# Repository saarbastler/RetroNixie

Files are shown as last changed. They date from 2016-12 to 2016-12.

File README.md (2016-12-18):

# RetroNixie

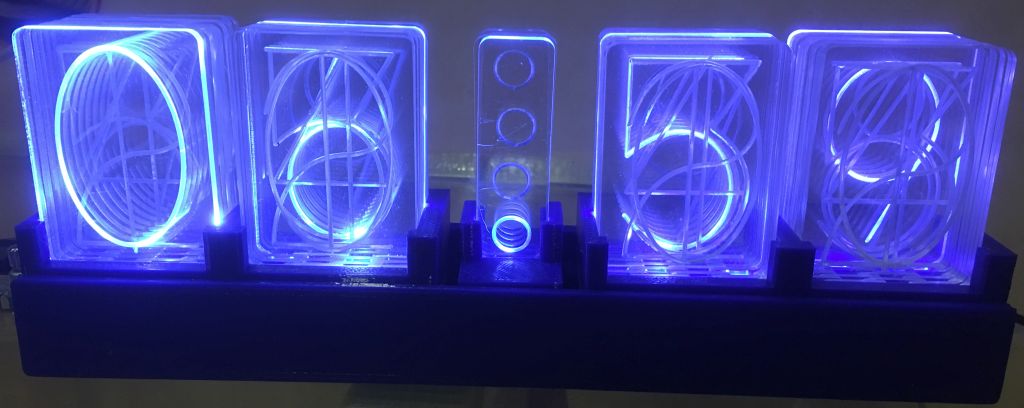
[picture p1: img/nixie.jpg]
Retro Nixie


RetroNixie is a 4 digit Clock looking like a Nixie tube clock, but is made of acrylic glass. Each digits has 10 acrylic glass slices, engraved with digits 0..9.
Each digit has got two WS2812 Led's, an ATMega328P controls the Led's to show the time.

See also on Thingiverse: (http://www.thingiverse.com/thing:1978456)

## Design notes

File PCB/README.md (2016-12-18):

# PCB Files

I'm using Target as PCB software. The Segment PCB is needed twice, the other once. The Clock is using an ATMega328P and a DS1307 as real time clock. A rotary encoder is used to set the time.

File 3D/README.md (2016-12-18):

# 3D Files

Designed in Open Scad. Print dualBoden.stl and vorne.stl twice and miniBoden once.

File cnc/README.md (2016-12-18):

# CNC Files

Use you favorite CAM software to generate the G Codes for you milling machine. I'm using [Estlcam](http://www.estlcam.com/) to generate the files for my [Stepcraft 420](https://www.stepcraft-systems.com/en/).

My machine is able to mill acrylic glass under water up to 30cm x 15cm. Three acrylic glass sheets are necessary to mill 4 * 10 digits and for smaller pieces with dots. first the digits are milled using a 45° graver, then use a 2mm milling tool to cut out the pieces.

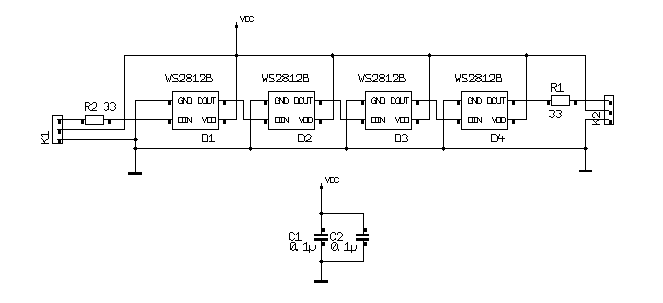
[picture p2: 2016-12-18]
PCB/DotsSegmentSchematics.png

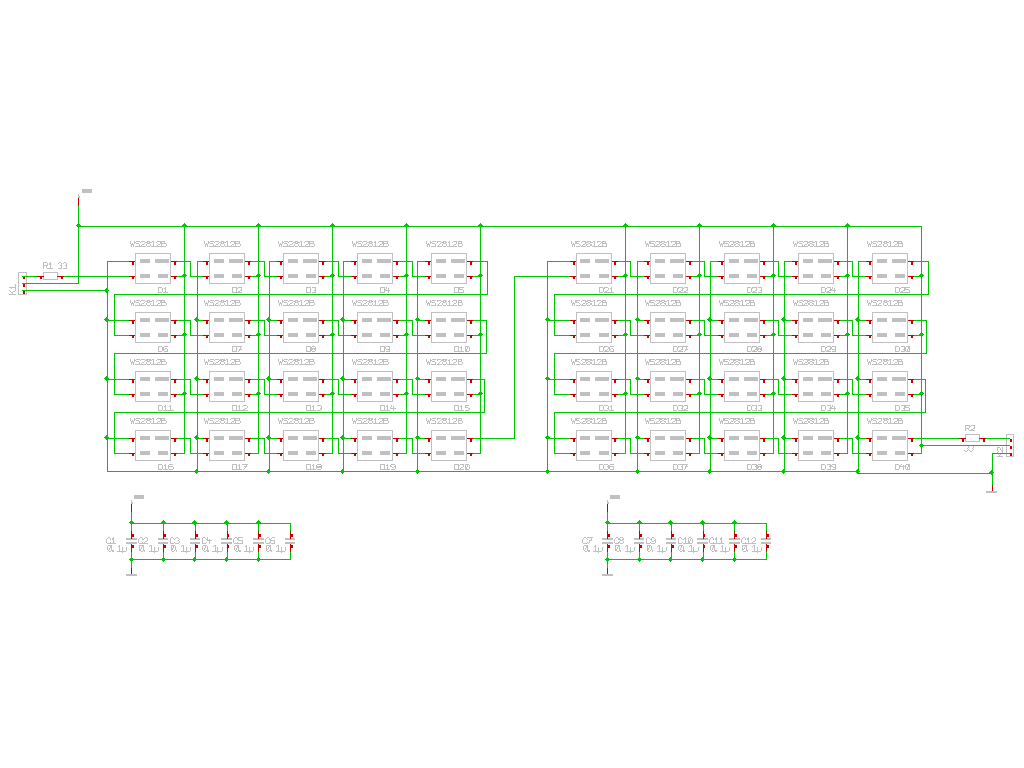
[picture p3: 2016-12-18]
PCB/DualDigitsSchematics.png

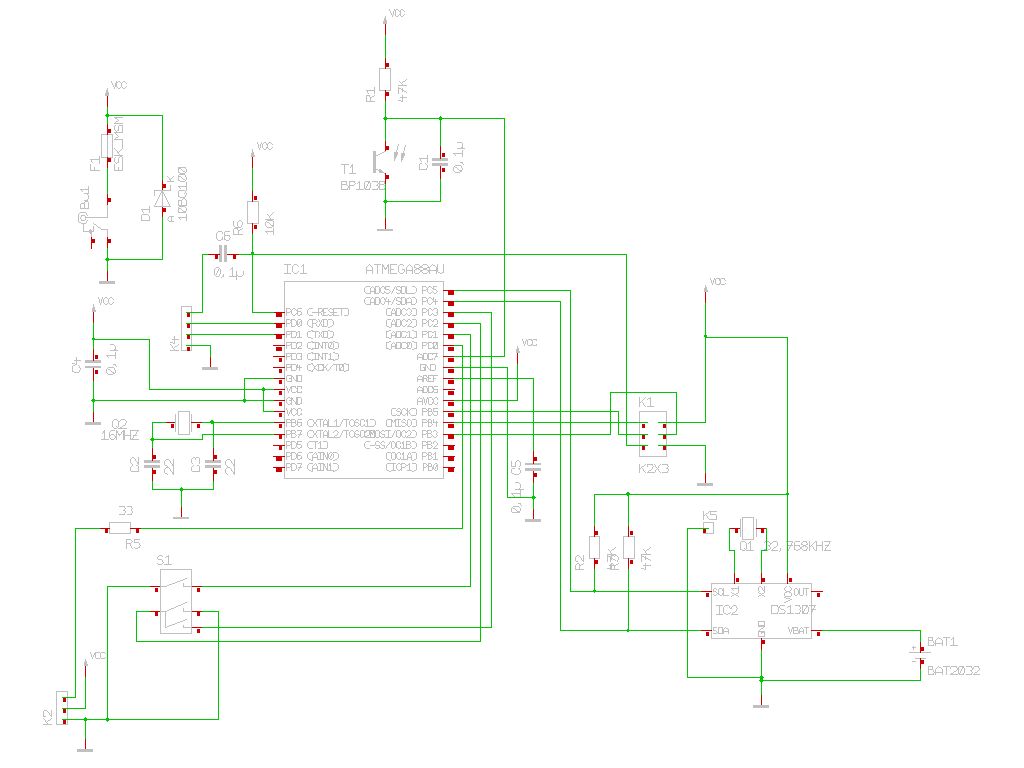
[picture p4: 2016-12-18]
PCB/ClockSchematics.png

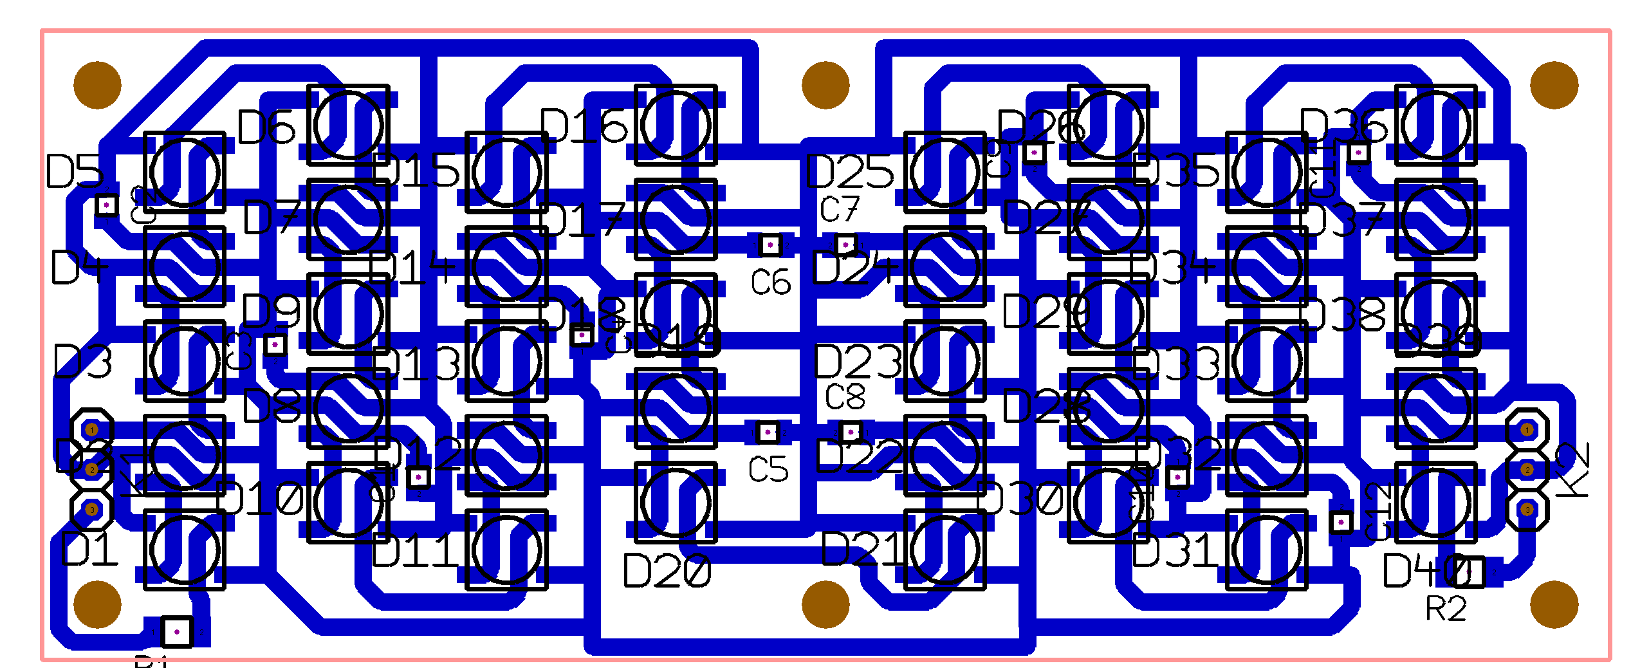
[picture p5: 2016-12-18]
PCB/DualDigitsPCB.png

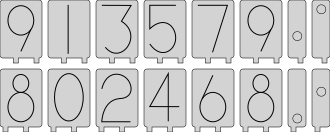
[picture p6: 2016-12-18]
cnc/digits3.png

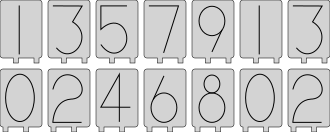
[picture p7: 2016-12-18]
cnc/digits1.png

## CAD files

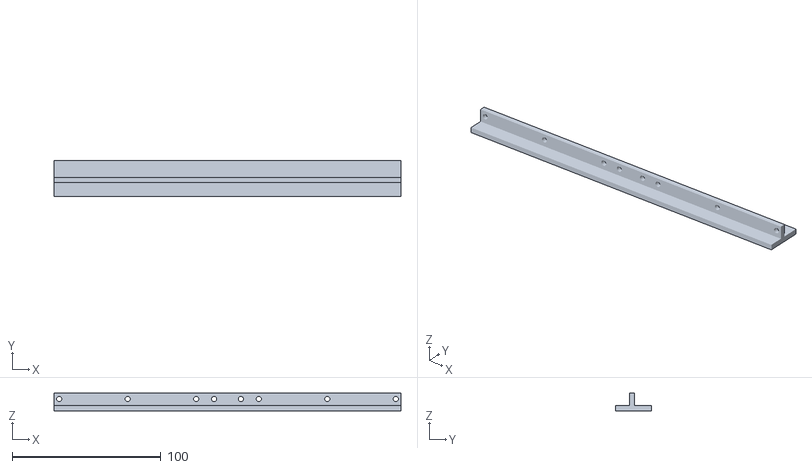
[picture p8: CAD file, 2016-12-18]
3D/vorne.stl
233.0 x 24.5 x 12.0

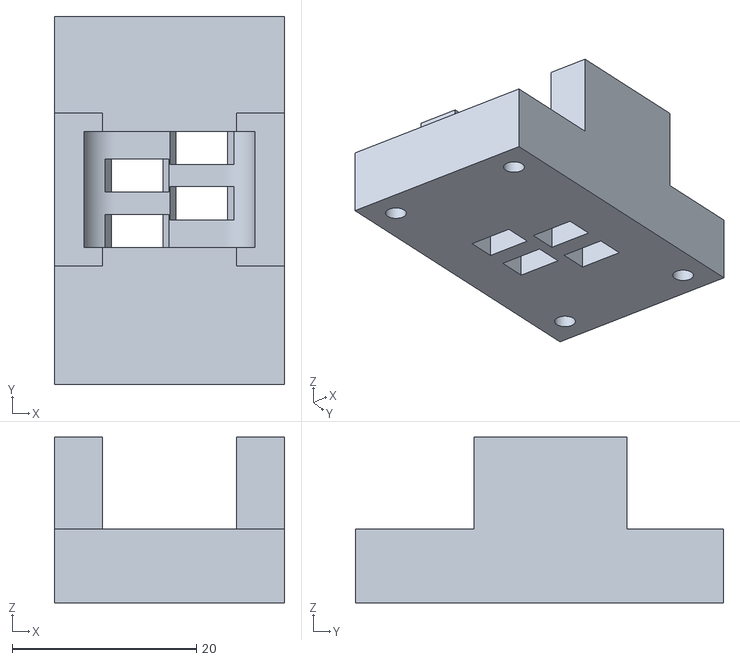
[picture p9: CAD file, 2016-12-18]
3D/miniBoden.stl
25.0 x 40.0 x 18.0

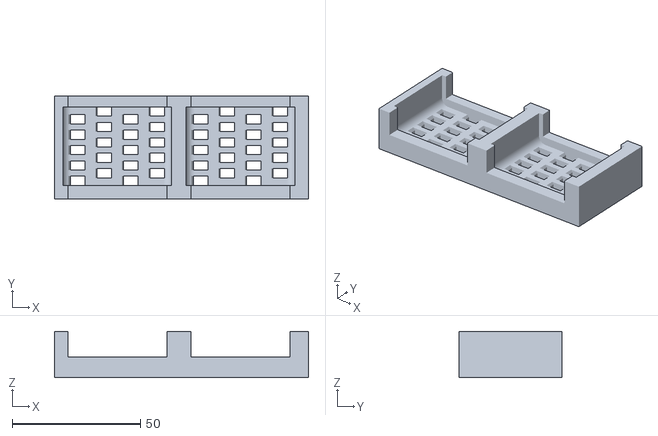
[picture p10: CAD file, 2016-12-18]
3D/dualBoden.stl
99.0 x 40.0 x 18.0

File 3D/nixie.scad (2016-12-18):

$fn=100;
addition= 0.3;

module ausschnitt()
{  
  rotate([90,0,0])translate([0,0,-1.5-addition])
  linear_extrude(height=3+2*addition)
    polygon(points=[[-2.5-addition,-1],[-2.5-addition,5-1-addition], [-2.5-1-addition,5+addition]
      , [2.5+1+addition,5+addition],[2.5+addition,5-1-addition],[2.5+addition,-1]
  
  ]);
}

module auschnittDigit()
{
  for(i=[0:4],n=[0:1])
  {
    translate([9+n*20.666,7+i*6,0]) ausschnitt();
    translate([9+10.333+n*20.666,10+i*6,0]) ausschnitt();
  }
  hull()
  {
    translate([6.5,7-1.5-addition,8])rotate([-90,0,0])cylinder(r=3+addition,h=30+2*addition);
    translate([42+.5,7-1.5-addition,8])rotate([-90,0,0])cylinder(r=3+addition,h=30+2*addition);
  }
  translate([3.5-addition/2,7-1.5-addition,8]) cube([42+addition,30+2*addition,20]);
}

module miniBoden()
{
  difference()
  {
    union()
    {
      cube([25,40,8]);
      
      difference()
      {
        translate([0,16.7-1.5-addition-2,8]) cube([25,12+(2+addition)*2,10]);
        
        translate([3.2+2,16.7-5,8]) cube([18.6-4,20,15]);
      }
    }
        
    translate([9,0,0]) 
    {
      translate([0,16.7,0]) ausschnitt();
      translate([7,16.7+3,0]) ausschnitt();
      translate([0,16.7+6,0]) ausschnitt();
      translate([7,16.7+9,0]) ausschnitt();
    }  
    
    hull()
    {
      translate([6.5,16.7-1.5-addition,8])rotate([-90,0,0])cylinder(r=3+addition,h=12+2*addition);
      translate([18+.5,16.7-1.5-addition,8])rotate([-90,0,0])cylinder(r=3+addition,h=12+2*addition);
    }
    
    translate([3.5-addition,16.7-1.5-addition,8]) cube([18+2*addition,12+2*addition,20]);
    
    translate([ 3.5, 3.5,-1]) cylinder(d=2.5,h=7);
    translate([ 3.5,36.5,-1]) cylinder(d=2.5,h=7);
    translate([21.5, 3.5,-1]) cylinder(d=2.5,h=7);
    translate([21.5,36.5,-1]) cylinder(d=2.5,h=7);

  }
}

module boden()
{
  difference()
  {
    union()
    {
      cube([99,40,8]);
      
      difference()
      {
        translate([0,0,8]) cube([99,40,10]);
        
        translate([3.2+2,-1,8]) cube([42+2*addition-4,50,15]);
        translate([48+3.2+2,-1,8]) cube([42+2*addition-4,50,15]);
      }
    }
    
    auschnittDigit();
    translate([48,0,0]) auschnittDigit();
    
    translate([ 3.5, 3.5,-1]) cylinder(d=2.5,h=7);
    translate([ 3.5,36.5,-1]) cylinder(d=2.5,h=6);
    translate([49.5, 3.5,-1]) cylinder(d=2.5,h=7);
    translate([49.5,36.5,-1]) cylinder(d=2.5,h=7);
    translate([95.5, 3.5,-1]) cylinder(d=2.5,h=7);
    translate([95.5,36.5,-1]) cylinder(d=2.5,h=7);
  }
}

module schraubAussparung()
{
  cylinder(d=3.5, h=10);
  cylinder(d=6.5, h=4.5);
}

module vorne()
{
  translate([0,-4.5,-5-3.75])
  {
    translate([0,0,-10]) cube([233,3.5,13]);
    *translate([0,0,-10]) cube([233,4,3]);
    difference()
    {
      translate([0,0,1.5]) cube([233,12,13]);
      translate([-1,3.5,5]) cube([240,20,20]);
      
      translate([ 3.5,8,-3]) schraubAussparung();
      translate([49.5,8,-3]) schraubAussparung();
      translate([95.5,8,-3]) schraubAussparung();
      
      translate([107.5,8,-3]) schraubAussparung();
      translate([107.5+18,8,-3]) schraubAussparung();
      
      translate([134,0,0])
      {
        translate([ 3.5,8,-3]) schraubAussparung();
        translate([49.5,8,-3]) schraubAussparung();
        translate([95.5,8,-3]) schraubAussparung();
      }
    }
  }
}

vorne();
translate([233,40,0]) rotate([0,0,180]) vorne();

boden();
translate([104,0,0]) miniBoden();
translate([134,0,0]) boden();

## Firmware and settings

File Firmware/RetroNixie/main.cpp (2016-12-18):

/*
 * MotorController.cpp
 *
 * Created: 04.10.2016 20:11:01
 * Author : Joerg
 */ 

#include <avr/io.h>
#include <avr/interrupt.h>
#include <avr/pgmspace.h>

#include "Device.h"
#include "Timer1.h"
#include "DelayTimerW.h"

#include "RetroNixieClock.h"
#include "I2CMaster.h"

/*extern "C"
{
  void __cxa_pure_virtual()
  {
    
  }
}*/

RetroNixieClock retroNixieClock;

int main(void)
{  
  sei();
  
  retroNixieClock.init();
  for(;;)
  {
    retroNixieClock.loop();
    idle();
  }
}

void idle()
{
  retroNixieClock.idle();
}

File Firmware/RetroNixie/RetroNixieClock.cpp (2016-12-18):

/* 
* RetroNixieClock.cpp
*
* Created: 20.11.2016 08:15:42
* Author: Joerg
*/

#include <avr/pgmspace.h>
#include <avr/io.h>
#include <string.h>

#include "Device.h"
#include "Timer1.h"

#include "RetroNixie.h"
#include "RetroNixieClock.h"

#include "I2CDS1307.h"
#include "I2CMaster.h"

#ifdef ENABLE_SERIAL_MONITOR
#include "PrintStream.h"
extern PrintStream out;
#endif

#define MODE_SHOW_TIME    0
#define MODE_SET_HOURS    1
#define MODE_SET_MINUTES  2
#define MODE_STORE_WAIT   3

// two bits red, green, blue. 00= off, 01= half bright, 10= full bright
const PROGMEM uint8_t RetroNixieClock::COLOR_BITS[] = { 
  /*0b000000, */0b000001, 0b000010, 0b000100, 0b000101, 0b000110, 0b001000, 0b001001, 0b001010,
  0b010000, 0b010001, 0b010010, 0b010100, 0b010101, 0b010110, 0b011000, 0b011001, 0b011010,
  0b100000, 0b100001, 0b100010, 0b100100, 0b100101, 0b100110, 0b101000, 0b101001, 0b101010 };
#define COLOR_BITS_SIZE     (sizeof(COLOR_BITS)/sizeof(COLOR_BITS[0]))

RetroNixieClock::RetroNixieClock() 
  : encoder(Timer1::getTickerLAddr(), this), 
  secondTimer( Timer1::getTickerAddr(), 100 ),
  milliseconds(0), seconds(0), time(0), timeInitialized(false)

{
  colorIndex= 0;
  brightness= 0x7f;
  setColor(brightness, colorIndex, color);

  off.r=0;
  off.g=0;
  off.b=0;

  mode= MODE_SHOW_TIME;
  clearDigitColor();

  ADMUX= _BV(REFS0) | /*_BV(ADLAR) |*/ 7;
  ADCSRA= _BV(ADEN) | _BV(ADATE) | _BV(ADIF) | 7;
  ADCSRB= 0;
  //DIDR0 = 1;

  ADCSRA |= _BV(ADSC);
  analogCount= 0;
  lastAnalogInput= 0;

  I2CMaster::init(80);
}

void RetroNixieClock::init()
{
  Timer1::init(  2, 14 );
  ICR1= 2000;

  LedString::init();
    
  secondTimer.start();    

  displayTime( time );
}

void RetroNixieClock::idle()
{
  encoder.cyclic();

  if( ADCSRA & _BV(ADIF) )
  {
    lastAnalogInput= ADC;
    analogIn += lastAnalogInput;
    ADCSRA= _BV(ADEN)  | _BV(ADATE) | _BV(ADIF) | 7;

    if( ++analogCount & 0xc0 )
    {
      analogCount= 0;
      setBrightness( 255 - (analogIn >> 8));
      analogIn= 0;
    }
  }
}

void RetroNixieClock::loop()
{
  if( secondTimer.isDone() )
  {
    secondTimer.start();
    milliseconds++;

    loop100ms();
  }
}

void RetroNixieClock::loop100ms()
{
  readRTC();

  if( ds1307.isDataAvailable() )
  {
    uint8_t dsSeconds= ds1307.getSeconds();
    if( seconds != dsSeconds )
    {
      milliseconds= 0;
      seconds= dsSeconds;
      time= ds1307.getHoursMinutes();

#ifdef ENABLE_SERIAL_MONITOR
      //out.printf_P( PSTR("TI: %wd %bd\r\n"), time, seconds);
#endif

      if( mode == MODE_SHOW_TIME)
      {
        displayTime( time );
      }
      else
      {
        uint8_t diff = *Timer1::getTickerLAddr() - modeTimeout;
        if( diff > 300 )
          setMode( MODE_SHOW_TIME );
      }
    }

    ds1307.resetDataAvailable();
  }

  timeSetLoop();
}

void RetroNixieClock::timeSetLoop()
{
  switch( mode )
  {
    case MODE_SET_HOURS:
    setColor( 15 + (setCounter<<4), setColorIndex, digitColor[0]);
    digitColor[1]= digitColor[0];

    if( setCounter >= 15 )
    {
      setCounterDir= -1;
    }
    else if( setCounter == 0 )
    {
      setCounterDir= 1;
      setColorIndex= (setColorIndex+1) % COLOR_BITS_SIZE;
    }

    setCounter += setCounterDir;
    
    RetroNixie::setNumber( timeSet, digitColor );
    LedString::transmit();
    break;
    case MODE_SET_MINUTES:
    setColor( 15 + (setCounter<<4), setColorIndex, digitColor[2]);
    digitColor[3]= digitColor[2];

    if( setCounter >= 15 )
    {
      setCounterDir= -1;
    }
    else if( setCounter == 0 )
    {
      setCounterDir= 1;
      setColorIndex= (setColorIndex+1) % COLOR_BITS_SIZE;
    }

    setCounter += setCounterDir;
    
    RetroNixie::setNumber( timeSet, digitColor );
    LedString::transmit();
    break;

    case MODE_STORE_WAIT:
    setColor( 15 + (setCounter<<4), setColorIndex, digitColor[0]);
    digitColor[1]= digitColor[0];
    digitColor[2]= digitColor[0];
    digitColor[3]= digitColor[0];

    if( setCounter != 0 )
    {
      setCounter--;
    }
    RetroNixie::setNumber( timeSet, digitColor );
    LedString::transmit();
    break;
  }
}

void RetroNixieClock::readRTC()
{
  if(!I2CMaster::isBusy())
  {
    if(ds1307.isModified())
    {
#ifdef ENABLE_SERIAL_MONITOR
      out.print_P(PSTR("write Device\r\n"));
#endif
      ds1307.writeDevice();

      if( I2CMaster::hasError())
      {
#ifdef ENABLE_SERIAL_MONITOR
        out.printf_P(PSTR("DS1307 Error: %bx\r\n"), I2CMaster::getError());
#endif
      }
    }
    else if( !ds1307.isDataAvailable() )
    {
#ifdef ENABLE_SERIAL_MONITOR
      if(!timeInitialized)
        out.print_P(PSTR("read Device\r\n"));
#endif
      ds1307.readDevice();
      
      if( I2CMaster::hasError())
      {
#ifdef ENABLE_SERIAL_MONITOR
        out.printf_P(PSTR("DS1307 Error: %bx\r\n"), I2CMaster::getError());
#endif
      }
      else
      {
        if( !ds1307.isClockEnabled() )
        {
          ds1307.enableClock(true);
        }
        else if(!timeInitialized)
        {
          seconds= ds1307.getSeconds();
          time= ds1307.getHoursMinutes();
          colorIndex= ds1307.getExtra(0);
          if( colorIndex >= COLOR_BITS_SIZE )
          colorIndex= 0;
        }

#ifdef ENABLE_SERIAL_MONITOR
        if(!timeInitialized)
        {
          for( BYTE b=0;b < 8;b++)
          {
            out.printHex( ds1307.buffer[b] );
            out.putch(' ');
          }
          out.crlf();
        }
#endif

        timeInitialized= true;
      }
    }
  }
}

void RetroNixieClock::setTime( uint16_t value )
{
  if( value < 2359 && (value%100) < 60)
  {
    seconds= 0;
    time= value;
    displayTime( time );

#ifdef ENABLE_SERIAL_MONITOR
    out.printf_P( PSTR("set time: %wd\r\n"), time);
#endif

    ds1307.setSeconds(seconds);
    ds1307.setHoursMinutes(value);

#ifdef ENABLE_SERIAL_MONITOR
    for( BYTE b=0;b < 8;b++)
    {
      out.printHex( ds1307.buffer[b] );
      out.putch(' ');
    }
    out.crlf();
#endif
  }
}

void RetroNixieClock::setBrightness( uint8_t b )
{
  if( b < MINIMAL_BRIGHTNESS )
    brightness= MINIMAL_BRIGHTNESS;
  else
    brightness= b;

  setColor(brightness, colorIndex, color);

  if( mode == MODE_SHOW_TIME )
    displayTime( time );
}

void RetroNixieClock::displayTime( WORD t )
{
  LedString::allOff();
  
  uint16_t b= brightness * ((seconds & 1) ? milliseconds : 10-milliseconds);
  uint8_t dotBrightness= b / 10;
  if( dotBrightness < MINIMAL_BRIGHTNESS )
    dotBrightness= MINIMAL_BRIGHTNESS;

  RGB_t dotColor;
  setColor( dotBrightness, colorIndex, dotColor);
  RetroNixie::setDot(seconds / 15, dotColor);

  RetroNixie::setNumber(t, color);

  LedString::transmit();
}
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

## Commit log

2016-12-18 §d Print files
    [dualBoden.stl, miniBoden.stl, nixie.scad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]
2016-12-18 PCB files
